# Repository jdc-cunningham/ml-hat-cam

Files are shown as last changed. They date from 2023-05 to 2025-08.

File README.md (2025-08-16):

### About

An auto-zoom hat-mounted camera using an Arducam IMX477 with 8-50mm lens and ML for rc plane detection

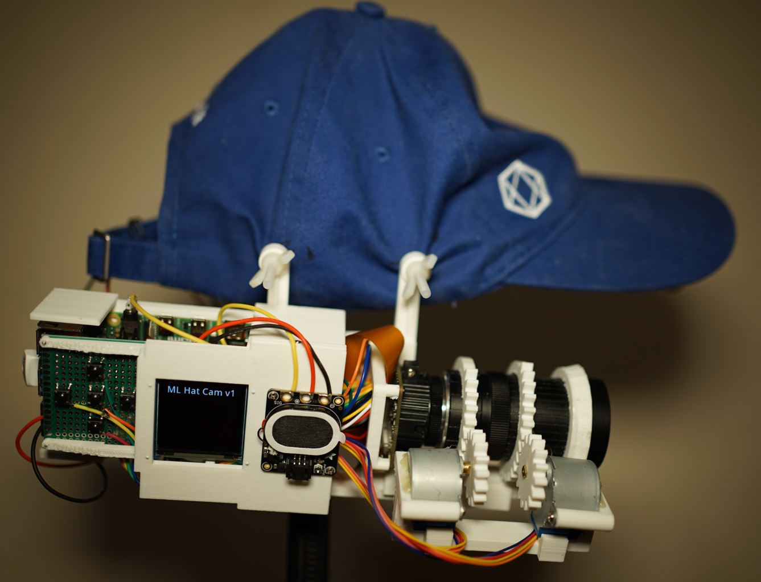
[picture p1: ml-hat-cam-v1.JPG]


[Focusing calibration video](https://youtu.be/QS5gliyjalo?si=H5IM7UlINm3g-GTi&t=10)

### Current capabilities
- record video, write to USB
- record audio, write to USB
- dpad with display (basic menus)
- zoom and position (db)
- autofocus (variance, needs work)
- battery life tracking
- TTS statuses

### Unit cost $235+

Major parts (more than $1 each)

| Name | Cost |
| --- | --- |
| RPi 4B 4GB | $55 (originally) |
| Arducam 12.3MP IMX477 | $74.99 |
| Arducam 8-50mm lens | $49.99 |
| 2x 28BYJ-48 Stepper | $3 ea. |
| 1.5in Waveshare OLED | $18.59 |
| 2x Panasonic NCR18650B 3400mAh | $8.99 ea. |
| Adafruit Speaker | $5.95 |
| mEZD41503A-A step-up converter | $14.33 |

### ML Capable Yet?

No

### Development progress

[see task list](/tasks.md)

### System block diagram (needs to be updated when final state determined)
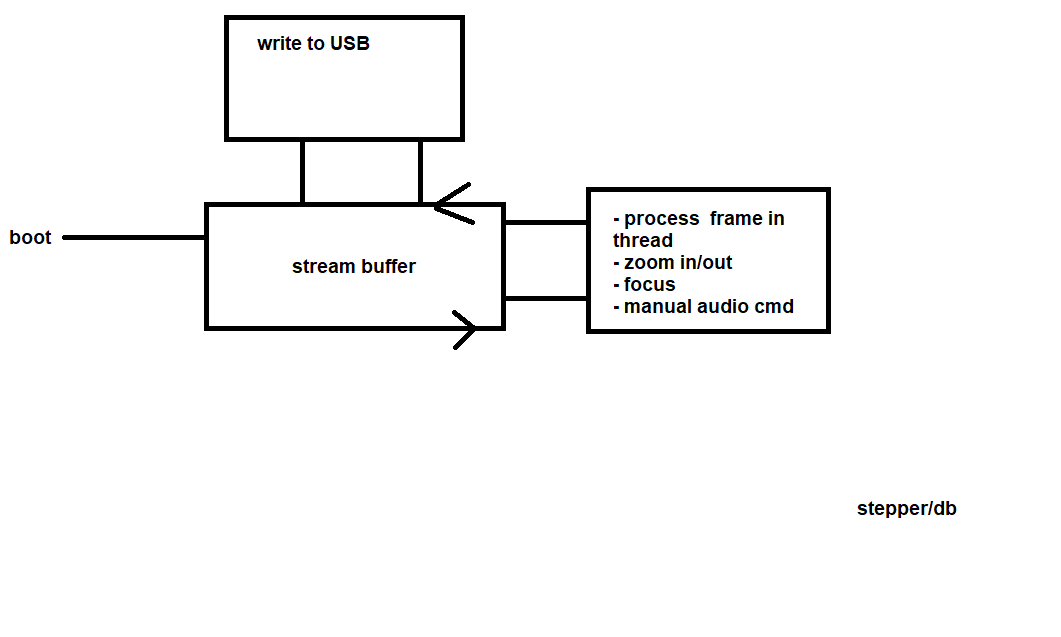
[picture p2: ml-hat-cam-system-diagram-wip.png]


### Raspberry Pi 4B GPIO pin usage

| Left | Right |
| --- | --- |
| 3.3V | 5V |
| GPIO 2 | 5V |
| GPIO 3 | Ground |
| GPIO 4 | GPIO 14 |
| Ground | GPIO 15 |
| GPIO 17 | GPIO 18 |
| GPIO 27 | Ground |
| GPIO 22 | GPIO 23 |
| 3.3V | **GPIO 24 [I]** |
| **GPIO 10 [D]** | Ground |
| **GPIO 9 [D]**  | **GPIO 25 [D]** |
| **GPIO 11 [D]** | **GPIO 8  [D]** |
| Ground | **GPIO 7  [I]** |
| **GPIO 0  [I]** | **GPIO 1  [I]** |
| **GPIO 5  [I]** | Ground |
| **GPIO 6  [S]** | **GPIO 12 [S]** |
| **GPIO 13 [S]** | Ground |
| **GPIO 19 [S]** | **GPIO 16 [S]** |
| **GPIO 26 [S]** | **GPIO 20 [S]** |
| Ground | **GPIO 21 [S]** |

Legend

- Steppers [S]
- Display [D] (uses 3.3V Linear Regulator for power)
- dpad [I] (input)

### Note

Avoid using `GPIO 1` this affects the camera (not detected).

It can be avoided if you don't have a shared ground connected but requires a switch until after boot.

### Disclaimer

Most of the physical dimensions on part models are not 100% accurate. They are for modeling the major dimensions for mounting/fitting in terms of volume.

This project might be a fail just because of how heavy/cumbersome it is.

A different approach is to use a tripod, ground-based tracker. Whether it tracks on its own or you aim with your head. The self-tracking sounds more interesting.

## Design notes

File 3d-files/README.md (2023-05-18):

### 3D Files

I used Google SketchUp (free) to design the parts in inches using calipers

I used an STL exporter plugin and solid inspector plugin

You can use Cura to slice the parts and print

The longest part to print is the bottom case (6.5 hrs)

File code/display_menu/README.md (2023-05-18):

### About

Uses Waveshare 1.5 OLED SSD1351

This is the basic interface to select model, start recording, transfer files, etc...

### Wiring

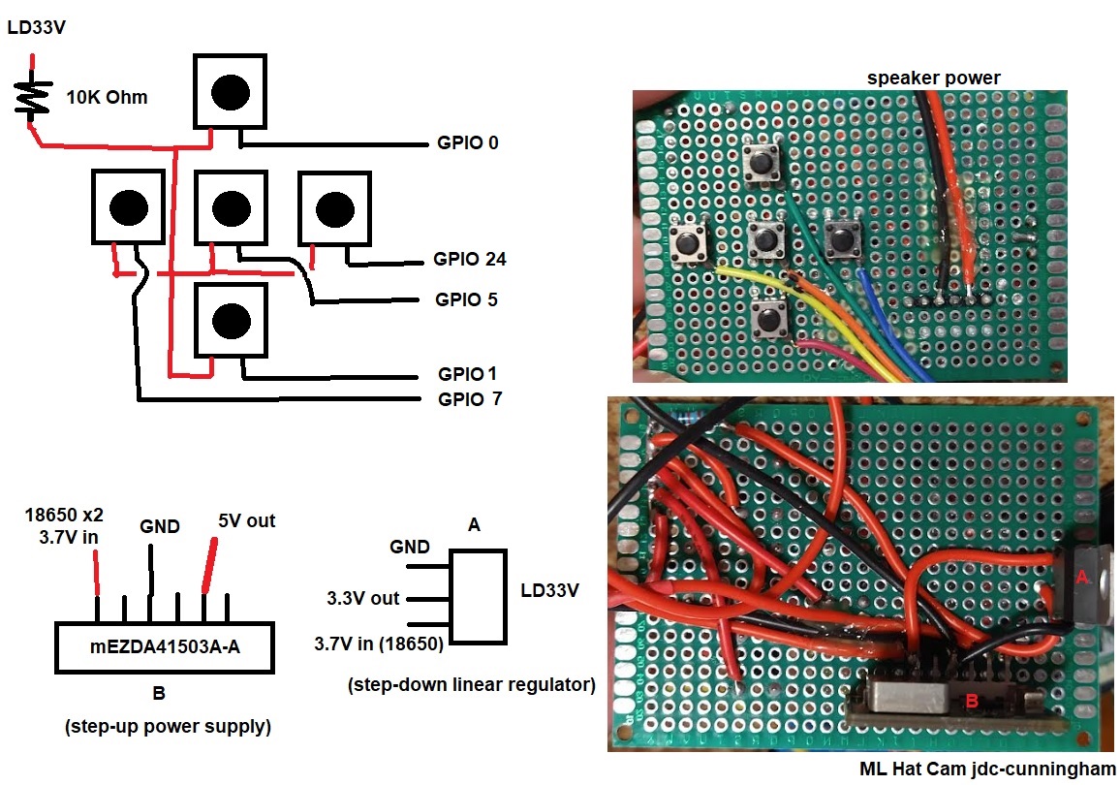
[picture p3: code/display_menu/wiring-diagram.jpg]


This powers the RPi through 5V pin and shares ground.

### OLED wiring info (specific to this project)

| OLED | RPi Pin |
| --- | --- |
| VCC (red) | 3.3V |
| GND (black)  | GND |
| DIN (blue) | GPIO 10 (MOSI) |
| CLK (yellow) | GPIO 11 (SCLK) |
| CS  (orange) | GPIO 8 (CE0) |
| DC  (green)  | GPIO 9 |
| RST (white)  | GPIO 25 |

DC and RST set in `~/OLED_Module_Code/OLED_Module_Code/RaspberryPi/python/lib/waveshare_OLED/config.py`

### Menu info

Menu path/operation
- charged? (yes/no)
  - this updates the battery uptime counter/resets it
    alternative would be to use an ADC to read battery voltage but not needed

Need to
- match pins picked out in this repo
- enable SPI through `raspi-config` see resource below
- install library
  - installed in home directory eg. `~`
  - note: wiringpi 64bit deb
    - https://raspberrypi.stackexchange.com/questions/137316/how-to-install-wiringpi-on-raspbian
    - https://github.com/WiringPi/WiringPi/releases/tag/2.61-1
- first run
  - no module named smbus
    - install python3-smbus
  - make sure pins match, their example was using what looks like a Pi 3
    - set in config.py of waveshare_OLED folder
  - DC and reset pin for me

Resources
- https://www.waveshare.com/wiki/1.5inch_RGB_OLED_Module

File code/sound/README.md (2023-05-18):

### Sound

Using pygame to play audio files

Using AWS Polly to generate specific sound (in advance) eg. "low battery"

### Volume control

```
GET volume: "amixer -M sget Headphone"
SET volume: "amixer -q -M sset Headphone 50%"
```

[source](https://forums.raspberrypi.com/viewtopic.php?t=233309)

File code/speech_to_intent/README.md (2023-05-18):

### Speech to intent

I am using Picovoice AI Rhino for these simple intents:

- zoom in
- zoom out

I made an account, I went on their site, went [here](https://console.picovoice.ai/rhn) to make my context (model)

Then I downloaded it after testing it in the browser

Install the demo see readme on [python](https://github.com/Picovoice/rhino)

Put it on the RPi so the demo command line call could reference it

`rhino_demo_mic --access_key ${ACCESS_KEY} --context_path ${CONTEXT_PATH}`

context_path is the path to the .rhn file

Then I execute this as a thread with references(callbacks) to functions fired by the intent, in this case zoom in or out (move stepper lens to certain positions eg. 0/mid/max)

See image for context



### About the implementation in this project

I installed the demo and I'm just using that demo comand line call and listening to the CLI out

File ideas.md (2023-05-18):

- use display for model select
- train againsat wall/airplane cutout on a stick (maybe handle is a problem)
  - can also use rod mounted to wall/not visible to cam
- pi 4/batter/display unit on left side, camera on right
- use some kind of cramping/clip thing to attach to hat brim

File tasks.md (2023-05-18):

### Progress
- [x] physical body (02/19/2023)
  - [x] usable lens focus/tele assembly (01/27/2023)
  - [x] display and dpad (02/17/2023)
  - [x] full design (attachable to hat) (02/19/2023)
- [ ] functionality code
  - [x] steppers and position tracking (02/09/2023)
    - [x] motion (01/28/2023)
    - [x] track in db for boot resume (02/09/2023)
  - [ ] menu design
  - [x] dpad bindings (02/18/2023)
  - [ ] record to USB
- [x] auto focus (02/12/2023)
  - [x] some method like comparing frames, more blurry go other way
    - used laplace variance
- [ ] auto zoom
  - use ML to find target, then zoom
- [ ] machine learning
  - train small shots of plane sillhouette against wall
  - record actual flying footage, label samples, train model

- [ ] record microphone sound
- [x] voice control to start things (some kind of model) (02/26/2023)
  - uses picovoice ai rhino speech to intent, only used `Zoom in` and `Zoom out`
- [x] battery db tracking (02/27/2023)
  - [x] show prompt on menu, if need to charge/play sound too

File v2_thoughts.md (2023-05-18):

- bump sensors for steppers
- rotate steppers so they're below lens
- IMU for determining sampling rate (motion = faster sampling)

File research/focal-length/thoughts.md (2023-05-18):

01/24/2023 10:23 PM

I don't know how big something is at some focal length... this lens goes from 8-50mm and my plane is a 1.5m wing span... how high up can I fly it before it's too small/a spec again.

https://www.omnicalculator.com/other/focal-length

sensor size is 1/2.3"

https://www.uctronics.com/lens/c-mount-lens/arducam-8-50mm-c-mount-zoom-lens-for-imx477-raspberry-pi-hq-camera-with-c-cs-adapter.html

From counting pixels... I got a magnification of 5.6x... expected with the zoom magnification is 4x

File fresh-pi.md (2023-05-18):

SD cards die

Trying to write video to USB drive

- boot
- sudo apt update
- sudo apt upgrade
- sudo apt dist-upgrade
- sudo apt install git
  - git ssh key, git global
- git clone
- sudo apt install python3-distutils
- wget https://bootstrap.pypa.io/get-pip.py
- python get-pip.py
  (reboot or source)
- pip install -r requirements.txt
- sudo nano /boot/config.txt
  - camera_auto_detect=0
  - dtoverlay=imx477

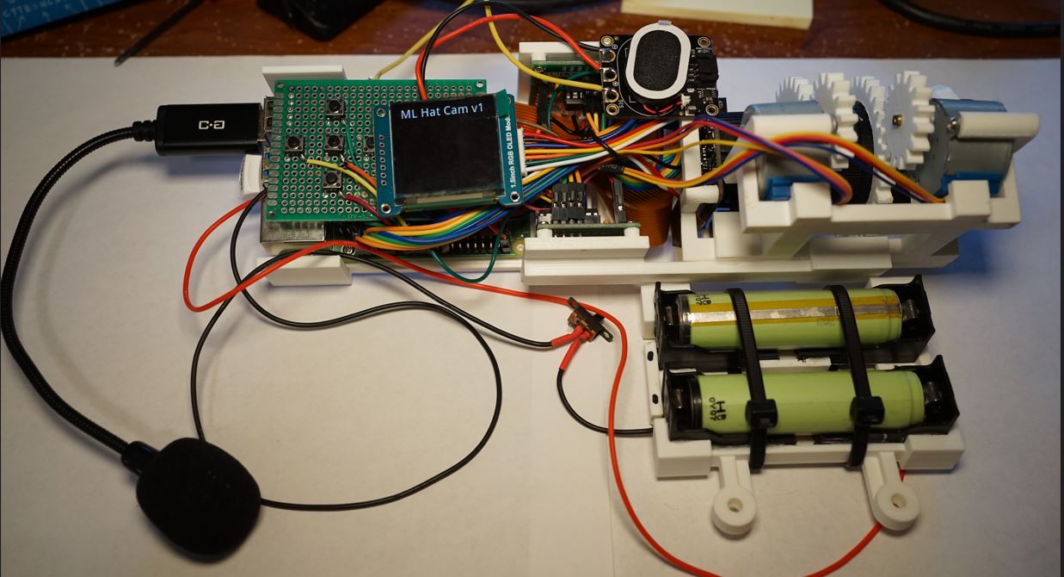
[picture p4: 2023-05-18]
mlhatcam-3.JPG

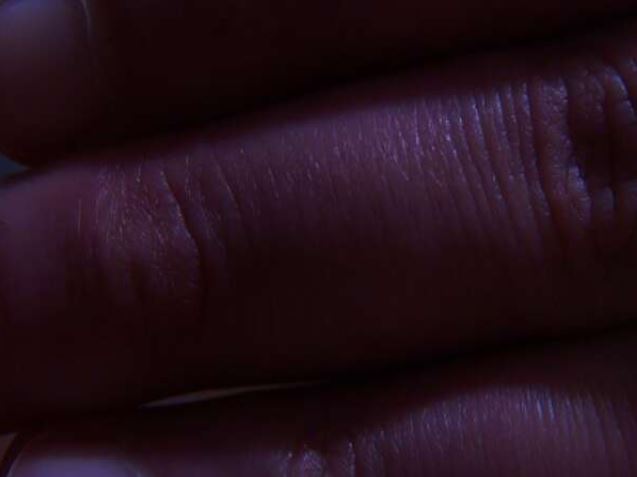
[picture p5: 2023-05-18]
misc/camera/check.JPG

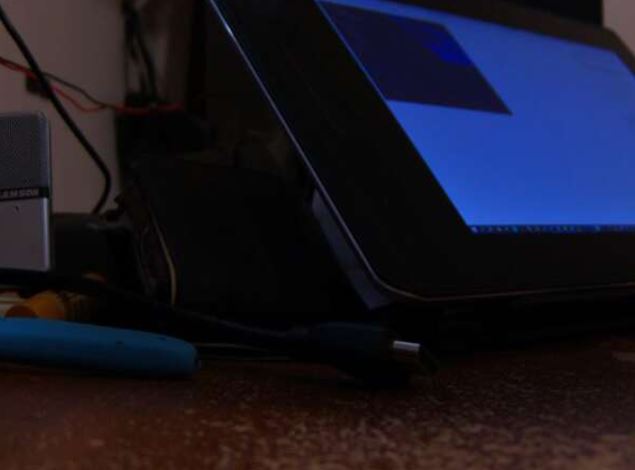
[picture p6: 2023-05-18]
misc/camera/in-focus.JPG

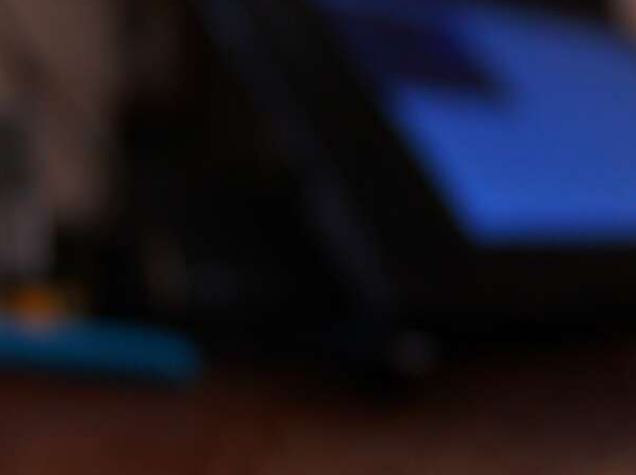
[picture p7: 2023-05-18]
misc/camera/blurry.JPG

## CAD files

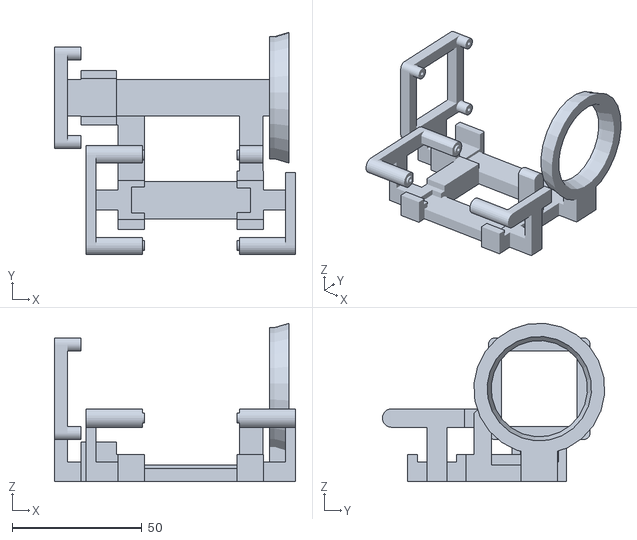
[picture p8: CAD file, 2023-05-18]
3d-files/stls/main-chasis.stl
92.8 x 85.6 x 61.0

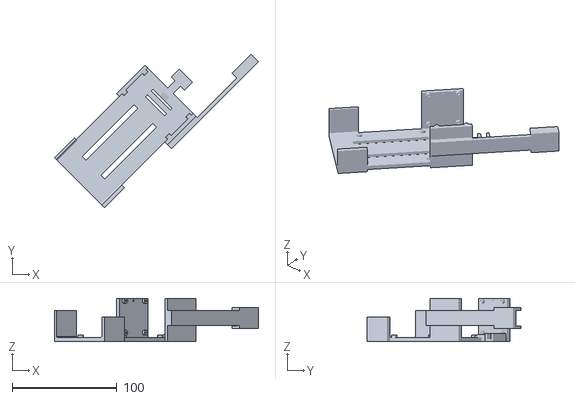
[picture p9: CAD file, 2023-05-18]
3d-files/stls/electronics-case-bottom.stl
194.4 x 146.3 x 41.1

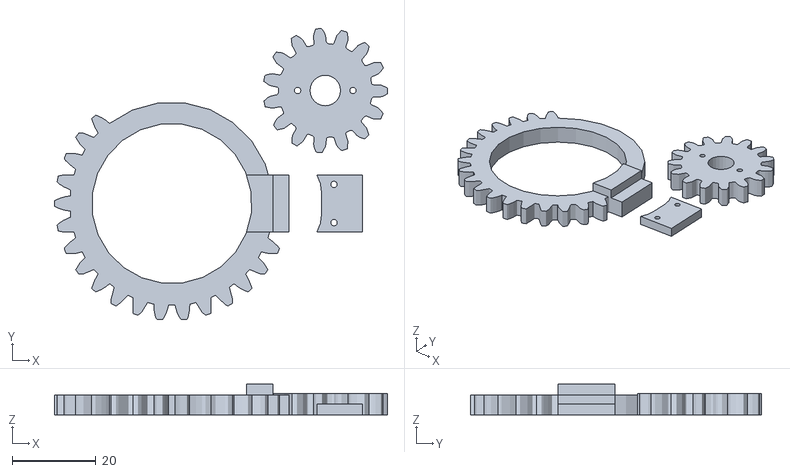
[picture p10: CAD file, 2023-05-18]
3d-files/stls/focus-ring-gear-set.stl
79.3 x 69.4 x 7.32

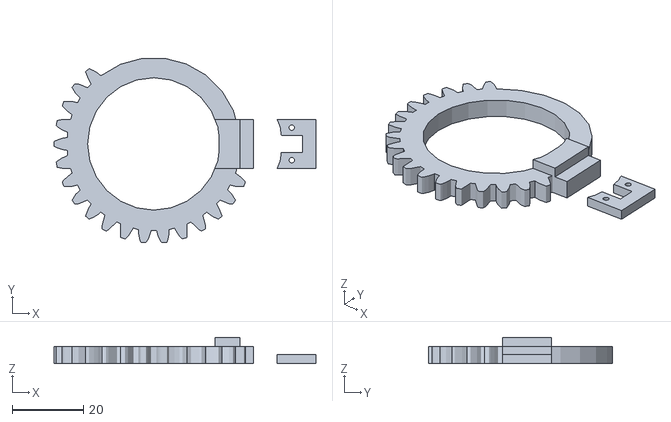
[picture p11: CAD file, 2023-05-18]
3d-files/stls/rotating-gear-set.stl
73.4 x 51.6 x 7.32

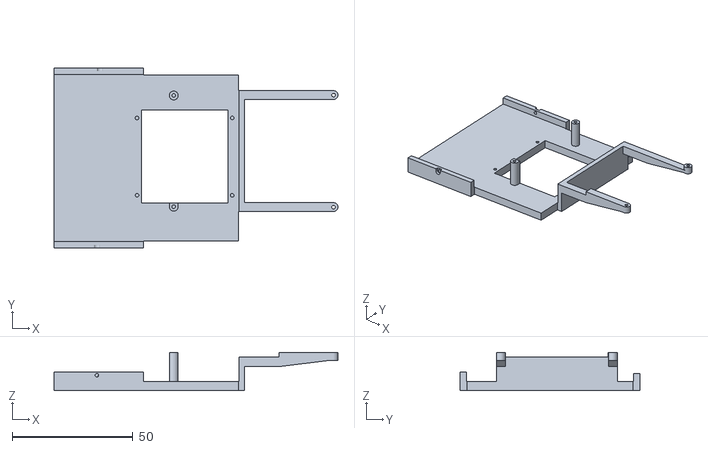
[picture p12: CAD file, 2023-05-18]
3d-files/stls/electronics-case-top.stl
117.8 x 74.5 x 15.8

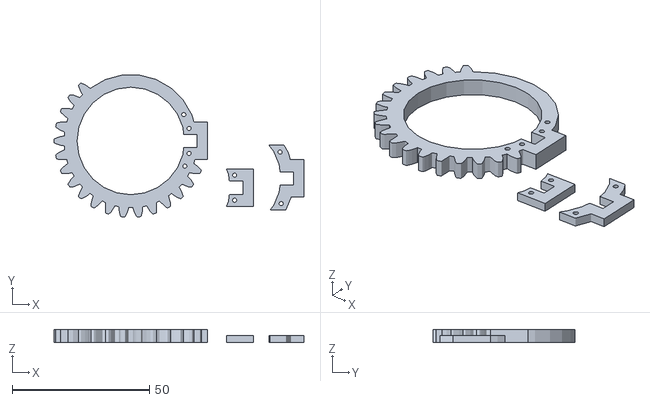
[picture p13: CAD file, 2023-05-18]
3d-files/stls/tele-ring-gear-set.stl
90.9 x 51.6 x 4.78

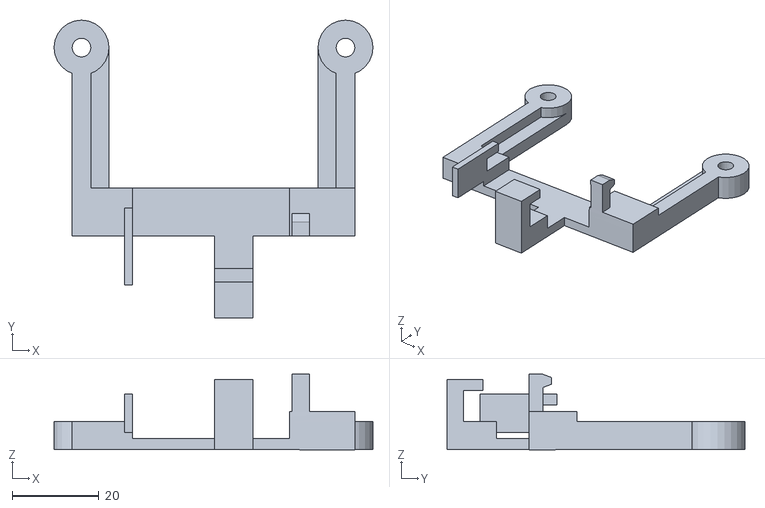
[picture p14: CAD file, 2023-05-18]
3d-files/stls/electronics-hanger.stl
73.7 x 68.8 x 17.4

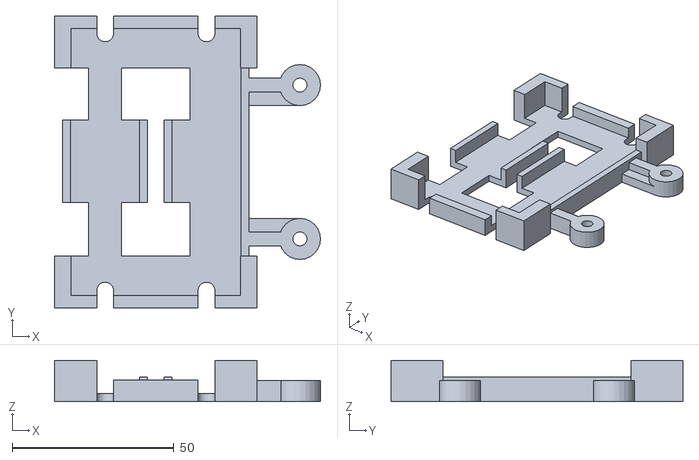
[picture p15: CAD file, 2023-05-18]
3d-files/stls/hat-battery-pack.stl
82.1 x 90.1 x 12.7

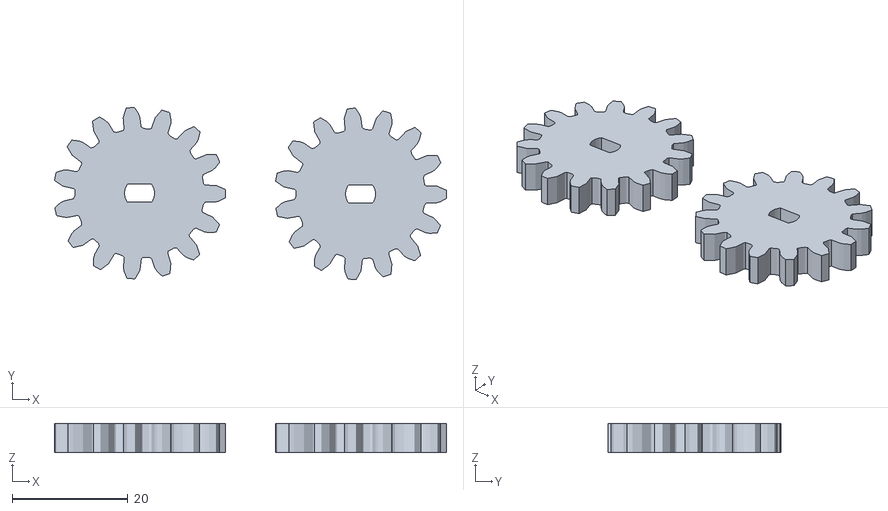
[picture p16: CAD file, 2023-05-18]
3d-files/stls/stepper-pinions.stl
67.6 x 29.8 x 5.08

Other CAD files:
3d-files/models/1.5-oled.skp
3d-files/models/18650-protected-cell.skp
3d-files/models/8-50mm-arducam-lens-cam.skp
3d-files/models/adafruit-speaker-0.skp
3d-files/models/adafruit-speaker.skp
3d-files/models/all-the-parts.skp
3d-files/models/assembly-with-gear-img.skp
3d-files/models/assembly.skp
3d-files/models/battery-pack-0.skp
3d-files/models/battery-pack.skp
3d-files/models/dpad-psus-protoboard.skp
3d-files/models/electronics-casae.skp
3d-files/models/electronics-case-0.skp
3d-files/models/electronics-case-bottom-0.skp
3d-files/models/electronics-case-bottom.skp
3d-files/models/electronics-case-top.skp
3d-files/models/electronics-case.skp
3d-files/models/electronics-hanger.skp
3d-files/models/focus-ring-gear-set.skp
3d-files/models/hat-battery-pack.skp
3d-files/models/main-chasis.skp
3d-files/models/mg90d.skp
3d-files/models/pi-4b.skp
3d-files/models/rotating-gear-set.skp
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

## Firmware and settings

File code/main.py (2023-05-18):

import os, pvrhino
from database.database import Database
from lens_stepper.stepper import Stepper
from camera.camera import start_web_stream
from dotenv import load_dotenv
from speech_to_intent.speech_to_intent import RhinoDemo
from threading import Thread
from sound.sound import Sound

player = Sound()

load_dotenv(os.getcwd() + "/speech_to_intent/.env")

db = Database()

focus_ring = Stepper(6, 13, 19, 26, 'focus', 350, db)
tele_ring = Stepper(12, 16, 20, 21, 'tele', 300, db)

def start_camera():
  start_web_stream(focus_ring, tele_ring)

def zoom_in():
  print("zoom in")

def zoom_out():
  print("zoom out")

zoom_level = 1 # 1, 2, 3 = close, middle, far

# zoom for wideopen
focus_ring.focus_far(320)

def parse_output(output):
  global zoom_level

  # tele vs. zoom
  # 0, 320
  # 150, 210
  # 300, 0

  if (output == 'ZoomIn' and zoom_level < 4):
    zoom_level += 1
    tele_pos = tele_ring.get_pos()

    if (tele_pos == 0): # to 150
      tele_ring.zoom_in(150)
      focus_ring.focus_near(120)
      player.play_sound_file('sound/files/aws_polly_medium-zoom.mp3')

    if (tele_pos == 150): # to 300
      tele_ring.zoom_in(150)
      focus_ring.focus_near(120) # get to 220
      player.play_sound_file('sound/files/aws_polly_max-zoom.mp3')

  if (output == 'ZoomOut' and zoom_level > 0):
    zoom_level -= 1
    tele_pos = tele_ring.get_pos()

    if (tele_pos == 300): # to 150
      tele_ring.zoom_out(150)
      focus_ring.focus_far(210)
      player.play_sound_file('sound/files/aws_polly_medium-zoom.mp3')

    if (tele_pos == 150): # to 0
      tele_ring.zoom_out(150)
      focus_ring.focus_far(110)
      player.play_sound_file('sound/files/aws_polly_wide-open.mp3')

def start_voice_listening():
  picovoice_ai_key = os.getenv('PV_AI_ACCESS_KEY')

  speechIntent = RhinoDemo(
    access_key=picovoice_ai_key,
    library_path=pvrhino.LIBRARY_PATH,
    model_path=pvrhino.MODEL_PATH,
    context_path=os.getcwd() + '/speech_to_intent/Zooming_en_raspberry-pi_v2_1_0.rhn',
    endpoint_duration_sec=1,
    require_endpoint=False,
    audio_device_index=1,
    output_path=None,
    output_callback=parse_output
  ).run()

Thread(target=start_voice_listening).start()
start_camera()

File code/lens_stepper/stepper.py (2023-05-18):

# references
# https://github.com/custom-build-robots/Stepper-motor-28BYJ-48-Raspberry-Pi/blob/master/decision-maker.py
# https://raspberrypi.stackexchange.com/questions/5100/detect-that-a-python-program-is-running-on-the-pi
import os

from time import sleep

on_pi = not(os.name == 'nt') # assumes only two OS environments

if on_pi: import RPi.GPIO as GPIO

class Stepper:
  from .stepper_steps import stepper_clockwise, stepper_counter_clockwise

  def __init__(self, pin1, pin2, pin3, pin4, name, max_pos, db):
    self.on_pi = on_pi
    self.IN1 = pin1
    self.IN2 = pin2
    self.IN3 = pin3
    self.IN4 = pin4
    self.step_wait_time = 0.001
    self.name = name
    self.min_pos = 0 # assumes calibrated at max stop one side
    self.max_pos = max_pos
    self.stop_moving = False
    self.db = db
    self.db_con = db.get_con()
    self.db_cur = db.get_cursor()
    self.cur_pos = db.get_stepper_pos(self.db_cur, self.name)
    self.db_update_pos = db.update_pos
    self.ignore_db = False
    self.GPIO = GPIO
    self.sleep = sleep

    if on_pi:
      self.init_gpio_pins()
      self.zero_stepper()

  def zero_stepper(self):
    prev_pos = self.get_pos()

    if (prev_pos > 0):
      if self.name == 'focus':
        self.focus_near(prev_pos)
      else:
        self.zoom_out(prev_pos)

    # self.focus_far(310) # neutral zoom about 13" away

  def init_gpio_pins(self):
    GPIO.setwarnings(False) # this is not great, but this class instance is not intended to be destroyed
    GPIO.setmode(GPIO.BCM)

    # set GPIO pins
    GPIO.setup(self.IN1,GPIO.OUT)
    GPIO.setup(self.IN2,GPIO.OUT)
    GPIO.setup(self.IN3,GPIO.OUT)
    GPIO.setup(self.IN4,GPIO.OUT)

    # set pins to false
    GPIO.output(self.IN1, False)
    GPIO.output(self.IN2, False)
    GPIO.output(self.IN3, False)
    GPIO.output(self.IN4, False)

  def get_pos(self):
    return self.db.get_pos(self.db_cur, self.name)

  def get_current_focal_length(self):
    step_per_mm = 7.14 # (50-8/300)
    return self.cur_pos * step_per_mm

  # this is a manual process, you need to catch the max pos by typing on keyboard/ssh
  # this should not have to be ran often
  # this is because the current physical design has no physical feedback on rotation position
  # other than focus of image
  def zero_stepper_manual(self):
    self.step_wait_time = 0.01 # really slow it down for safety
    self.ignore_db = True

    try:
      while True:
        if (self.name == 'tele'):
          self.zoom_out(1)
        else:
          self.focus_near(1)
    except KeyboardInterrupt:
      # back up, this is a source of error
      if (self.name == 'tele'):
        self.zoom_in(15)
      else:
        self.focus_far(15)
      self.update_stepper_db_pos(0)
      self.stop_moving = True
      self.ignore_db = False

  def update_cur_pos(self, steps, step_op):
    if (step_op == 'subtract' and (self.cur_pos - steps) < 0):
      return False

    if (step_op == 'add' and (steps + self.cur_pos) > self.max_pos):
      return False

    if step_op == 'add':
      self.cur_pos = self.cur_pos + steps
    else:
      self.cur_pos = self.cur_pos - steps

    return True

  def update_stepper_db_pos(self, step):
    self.db_update_pos(self.name, step, self.db_con, self.db_cur)

  # the steppers face each other/rotations are flipped
  # self.on_pi check skips calling steppers if no on pi
  def zoom_in(self, steps):
    if (self.name == 'focus'): return False
    if (not self.update_cur_pos(steps, 'add')): return False
    moved = True if not self.on_pi else self.stepper_clockwise(steps)
    if self.ignore_db: return False
    if moved: self.update_stepper_db_pos(self.cur_pos)

  def zoom_out(self, steps):
    if (self.name == 'focus'): return False
    if (not self.update_cur_pos(steps, 'subtract')): return False
    moved = True if not self.on_pi else self.stepper_counter_clockwise(steps)
    if self.ignore_db: return False
    if moved: self.update_stepper_db_pos(self.cur_pos)

  def focus_near(self, steps):
    if (self.name == 'tele'): return False
    if (not self.update_cur_pos(steps, 'subtract')): return False
    moved = True if not self.on_pi else self.stepper_counter_clockwise(steps)
    if self.ignore_db: return False
    if moved: self.update_stepper_db_pos(self.cur_pos)

  def focus_far(self, steps):
    if (self.name == 'tele'): return False
    if (not self.update_cur_pos(steps, 'add')): return False
    moved = True if not self.on_pi else self.stepper_clockwise(steps)
    if self.ignore_db: return False
    if moved: self.update_stepper_db_pos(self.cur_pos)

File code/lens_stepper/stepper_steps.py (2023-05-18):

def step_1(self):
  self.GPIO.output(self.IN4, True)
  self.sleep(self.step_wait_time)
  self.GPIO.output(self.IN4, False)

def step_2(self):
  self.GPIO.output(self.IN4, True)
  self.GPIO.output(self.IN3, True)
  self.sleep(self.step_wait_time)
  self.GPIO.output(self.IN4, False)
  self.GPIO.output(self.IN3, False)

def step_3(self):
  self.GPIO.output(self.IN3, True)
  self.sleep(self.step_wait_time)
  self.GPIO.output(self.IN3, False)

def step_4(self):
  self.GPIO.output(self.IN2, True)
  self.GPIO.output(self.IN3, True)
  self.sleep(self.step_wait_time)
  self.GPIO.output(self.IN2, False)
  self.GPIO.output(self.IN3, False)

def step_5(self):
  self.GPIO.output(self.IN2, True)
  self.sleep(self.step_wait_time)
  self.GPIO.output(self.IN2, False)

def step_6(self):
  self.GPIO.output(self.IN1, True)
  self.GPIO.output(self.IN2, True)
  self.sleep(self.step_wait_time)
  self.GPIO.output(self.IN1, False)
  self.GPIO.output(self.IN2, False)

def step_7(self):
  self.GPIO.output(self.IN1, True)
  self.sleep(self.step_wait_time)
  self.GPIO.output(self.IN1, False)

def step_8(self):
  self.GPIO.output(self.IN4, True)
  self.GPIO.output(self.IN1, True)
  self.sleep(self.step_wait_time)
  self.GPIO.output(self.IN4, False)
  self.GPIO.output(self.IN1, False)

def stepper_clockwise(self, steps):
  for i in range(steps):
    if (self.stop_moving == True):
      return False

    # print("c " + str(i))
    step_8(self) # could put these in an array, call them that way, reverse
    step_7(self)
    step_6(self)
    step_5(self)
    step_4(self)
    step_3(self)
    step_2(self)
    step_1(self)

  return True

def stepper_counter_clockwise(self, steps):
  for i in range(steps):
    if (self.stop_moving == True):
      return False

    # print("cc " + str(i))
    step_1(self)
    step_2(self)
    step_3(self)
    step_4(self)
    step_5(self)
    step_6(self)
    step_7(self)
    step_8(self)
  
  return True
  
